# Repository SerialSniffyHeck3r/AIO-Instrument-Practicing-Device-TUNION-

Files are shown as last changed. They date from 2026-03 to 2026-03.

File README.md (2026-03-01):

# STM32F4 Portable Practice DSP Device

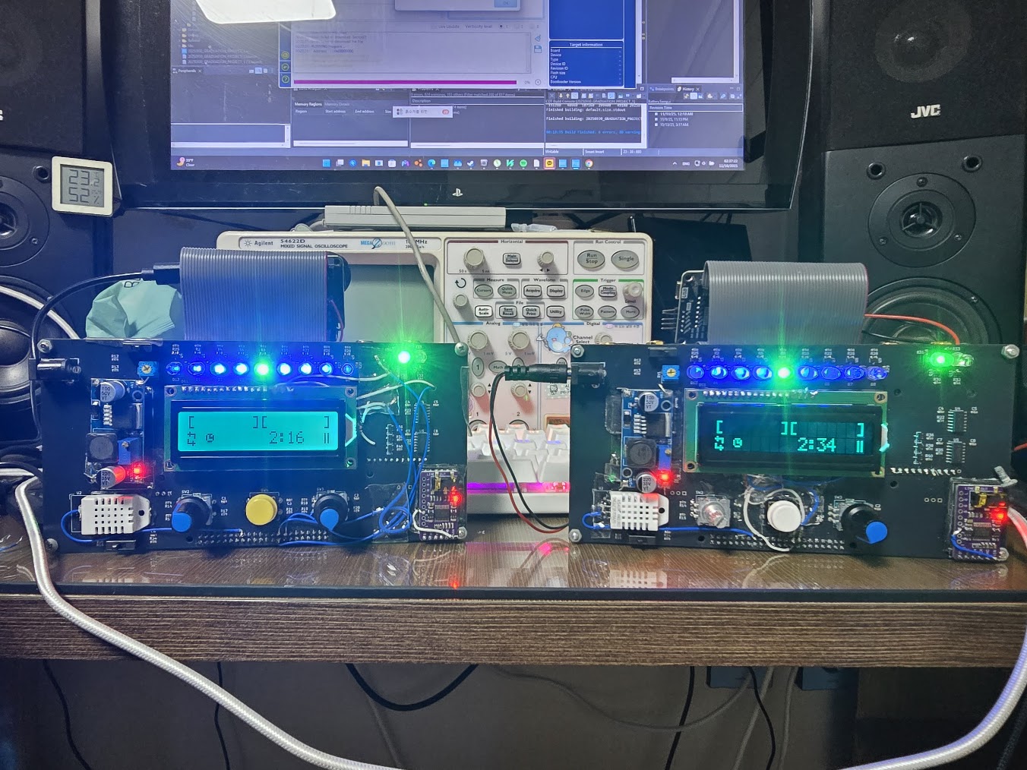
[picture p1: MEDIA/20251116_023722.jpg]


## Videos

https://www.youtube.com/watch?v=_CYvJwdOhUQ  Recovering Data

https://www.youtube.com/watch?v=7vPy3JID6l4  System Settings

https://www.youtube.com/watch?v=G-kPSslMNc0  BPM Auto Calculation

https://www.youtube.com/watch?v=HqbBY2KLgDY  Hardware Self Test

https://www.youtube.com/watch?v=8V4moodQUs4  Music Play Mode

https://www.youtube.com/watch?v=r6egSswZjCg  Notch Filter Applied

https://www.youtube.com/watch?v=-oUxMyITEes  Pitch Shifter Applied

https://www.youtube.com/watch?v=r_tZYo8vfbs  Volume Sound Effect

## Overview

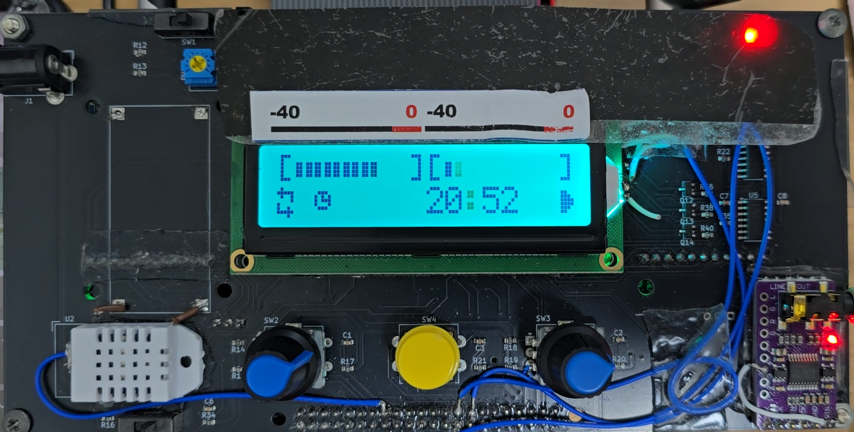
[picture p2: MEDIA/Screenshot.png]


This was developed for my bachelor graduation project, but with keeping in mind that the device will be used personally.. or crowdfunded.
It turned out it wasn't that good to be crowdfunded.. but still it works! and also good for my personal use.

This project focuses on developing a **portable practice companion** built around an **STM32F407** microcontroller.  
The device helps people practice instruments at home or in a rehearsal room without that huge amount of bulky gears.

## TL;DR (for recruiters)

- **Platform:** STM32F407, dual I2S audio, RGB 16x2 LCD, LED bar, rotary encoder, Li-ion battery
- **Focus:** Real-time audio DSP for instrument practice (notch filter, pitch shift, mixer), tuner, metronome
- **Reliability:** Flash config storage with CRC and wear-leveling, backup SRAM snapshot, factory self-test mode
- **Result:** Fully working handheld prototype with custom PCB, firmware, and UX

## STM32F4 기반 악기 연습 장치 'Tunion': 한국어 설명

해당 레포지토리는 본인의 졸업 작품으로써 설게한 제품에 대해 다루고 있습니다.

가정 및 연습실 환경에서는 악기를 크게 연주할 수 없어 뮤트를 착용하거나 전자 악기를 연주하게 된다는 문제 의식에서 출발하였으며, 악기 케이스에 항상 휴대하고 다닐 수 있으면서 악기를 연주할 때 바로 꺼내서 사용할 수 있는 만능 장비를 목표로 개발되었습니다. 
- 반주를 듣고, 반주가 없을 때 아무 음원이나 틀어서 Notch Filter를 적용하여 본인이 연주하는 악기 대역만 잘라서 그 부분과 본인의 악기 소리를 같이 들으면서 연습하거나
- 비트 및 서브비트 등 다양한 기능이 포함된 메트로놈 소리를 들으면서 반주도 같이 듣고 그 소리에 맞춰 악기를 연습하거나
- 악기를 조율하거나
- 또는 악기를 적절한 온습도의 환경에서 보관할 수 있게 하는 것

을 목표로 두고 있습니다.

본 기기의 기능은 다음과 같습니다:
- 악기로부터 들어오는 악기 소리 아날로그 입력 / 음향기기로부터 들어오는 반주 입력을 믹싱 및 개별 볼륨 조절
- 반주에서 본인이 연주하고자 하는 악기 대역을 자를 수 있는 Notch Filter를 적용해서 악기 소리와 믹싱
- HSE를 통해 달성한 고정밀 메트로놈, Sub-Beat, Tap Tempo, 리타르단도 기능을 포함하는 시중에도 찾아보기 힘든 다기능 메트로놈
- 악기 튜너 및 펑션 제너레이터
- 환경설정 및 Flash와 백업 SRAM에 환경설정 다중 백업
- Real-Time Clock, 연습 시간 기록 기능
- 실제 생산을 위한 하드웨어 셀프 테스트 (RAM, Flash 접근 시간 테스트, LCD 및 오디오 출력 테스트)
- 스스로의 펌웨어를 알아서 '죽이는' 히든 커맨드

### 기기 내부 저장 방식

본인을 레트로 컴퓨팅에 관심이 많으며, 레트로 컴퓨팅을 연구하거나 임베디드 시스템을 개인적으로 연구하면서 생긴 아이디어를 적용했습니다.

MCU와 내부 RAM이 살아 있는 상황에서
- Flash에 저장하는 경우: 홈 화면으로 복귀 / 절전 모드에서 탈출했을 때 설정 값이 이전과 변화했을 경우에만 Write
- BKPSRAM에 저장하는 경우: 모든 버튼이 조작되었을 때. Overhead가 낮아 최대 1초에 30번을 조작해도 시스템의 동작 안정성을 저해하지 않는다는 판단.

전원이 완전히 차단되었으나 백업 전지는 살아 있는 경우:
- 전원 인가시 BKPSRAM의 값 확인 후, Magic Number (0xDEADBEEF) Check
- 백업 전지가 살아 있으므로 Magic Number가 그대로 있으므로 유효하다고 판단하여, BKPSRAM에서 바로 값을 불러옴

전원이 완전히 차단되고 백업 배터리까지 빠졌을 경우:
- 전원 인가시 BKPSRAM의 값 확인 후 Magic Number가 유효하지 않음을 확인
- 사용자에게 Recover Data? YES / NO 인터페이스를 통해, 백업 배터리 분리가 초기화를 위한 의도적 행동인지 확인.
- 만약 YES를 선택했을 경우, FLASH에서 값을 복원. NO를 선택했을 경우 시스템 설정이 출고 시와 동일하게 초기화됨.
- 어차피 백업 배터리가 분리되었으면 **당연히** RTC도 유효하지 않을 것이므로, Yes / No 선택 유무에 상관없이 시계 재설정 유도
- 이후 정상 부팅 

---

## Backstory

I play lots of instrument from woodwinds to percussion. Music is pretty much literally my life. 
When I practice guitar or other instruments at home, 
I usually need shitloads of separate devices: audio interface, mixer, tuner, metronome, maybe a laptop? a phone??

So this is the backstory. I just wanted a **single small device** that can do all of these, while maintaining the functionality.
This is a graduation project, but my intention was to make something that is actually useful and is potentially lucrative.

The function that I planned to implement was:
- mix backing track and my instrument,
- remove some frequency range (for example vocals),
- quickly transpose the song,
- show audio level
- tuner and metromone with lots of features
- features that every portable embedded device that is on sale should have

So I designed and built this device as my **bachelor graduation project**.

---

## What this device does

From a user point of view, this box is:

- A **small mixer** for two stereo audio sources
- A **practice helper** that can cut or change a specific frequency band, then mix audio with my instrument sound
- A **digital tuner** with 1 cent resolution
- A **metronome** with different time signatures and tempo changes
- A **status monitor** for battery, temperature, humidity and system state

All of this runs on one STM32F407 MCU with no external DSP chip.

---

## Main features

### 1. Real-time audio DSP pipeline

- Two I2S inputs (for example: backing track + instrument/mic)
- DMA double-buffered ring pipeline (16-bit audio → float → processed → 16-bit)
- **Real-time mixing** of both channels with:
  - 50-step digital volume for each channel
  - master volume and balance
  - dBFS level meters for input level check

### 2. Adjustable band-cut / notch filter for practice

- User can select a **frequency range to cut** (for example vocal range)
- Implemented with **ARM CMSIS-DSP IIR biquad filters**
- Supports:
  - on/off control from the UI
  - start / end frequency
  - **three user presets** per instrument (saved in non-volatile memory)

This lets me listen to a song while removing or reducing the part I want to practice over.

### 3. Simple pitch shift for fast transposition

- Integrated **pitch shift** engine for quick transpose
- Control in **semitones** (for example −3…+3)
- Focus is on **low latency** and “good enough for practice”,  
  not studio-quality offline processing

### 4. Integrated tuner

- **Digital chromatic tuner** with 1-cent resolution
- AMDF-based pitch detection with:
  - harmonic / octave correction
  - pre-lock and lock logic to avoid jumping notes
- Adjustable:
  - **A4 base frequency** (calibration)
  - input sensitivity

The tuner drives both the LCD and the LED bar for visual feedback.

### 5. Sample-accurate metronome & tone generator

- Metronome audio is generated **inside the same DSP pipeline** as the audio
- Features:
  - accents and sub-clicks
  - tempo changes (ritardando / accelerando / back to a-tempo)
  - separate metronome volume
- Extra **sound generator mode** (sine / square / triangle)  
  for tuning or quick tests.

### 6. User interface and UX

- **RGB 16x2 character LCD** (HD44780-compatible)
  - custom UI pages for each mode (practice, tuner, metronome, settings)
- **LED bar** driven by PWM:
  - VU meter for input / mic levels
  - tuner center indication
  - metronome visualization
- **Rotary encoder + buttons**:
  - used for navigation and parameter editing
  - single short/long click design so it can be used while holding an instrument

I tried to keep the UI simple enough to use with one hand.

### 7. Power, environment and settings

- Powered from a **single Li-ion battery**
- Battery:
  - voltage measurement and level estimation
  - low-battery handling
- **Temperature & humidity** sensor (DHT22):
  - shows instrument storage environment
- **Config storage:**
  - main storage in Flash (sector with custom format)
  - record format with version, sequence number and CRC32
  - background service that only writes when values changed
- **Backup snapshot:**
  - second copy in backup SRAM,  
    so the device can restore settings quickly after a battery change

### 8. Factory / test mode

- Hidden button combo opens a **self-test mode**
- Used for:
  - LCD and LED test
  - audio path test
  - peripheral checks
- This was designed with **future production / repair** in mind.

---

## Hardware overview

- MCU: **STM32F407** (Cortex-M4 with FPU and DSP extensions)
- Audio:
  - Dual I2S interface
  - 16-bit stereo in/out
- UI:
  - HD44780-compatible RGB 16x2 LCD
  - 10-segment (or similar) LED bar
  - rotary encoder + buttons
- Sensors:
  - DHT22 temperature / humidity
  - battery voltage measurement
- Power:
  - Li-ion battery
  - backup power for RTC and SRAM

Custom PCB was designed so that the device is actually **hand-held and portable**. 

---

## Firmware / code structure (short version)

The firmware is written in **C** using the STM32 HAL and CMSIS-DSP.

- `main.c`  
  - main UI state machine, mode handling, LCD updates
- `notch.c`  
  - audio DSP pipeline, I2S callback, mixing, notch filter, pitch shift, metronome, sound generator
- `tuner.c`  
  - pitch detection and note / cent calculation
- `LEDcontrol.c`  
  - LED bar effects, VU meter and tuner / metronome visualization
- `BatteryTemp.c`, `dht.c`  
  - battery and DHT22 handling
- `PowerFlash.c`  
  - Flash config storage with CRC and wear-leveling
- `PowerSave.c`  
  - backup SRAM snapshot for fast resume
- `Clock.c`  
  - RTC time setting UI

The code is clearly not perfect, as this is one of my first huge system architect project.
but it is a complete prototype that I could really use as my **daily practice companion**.

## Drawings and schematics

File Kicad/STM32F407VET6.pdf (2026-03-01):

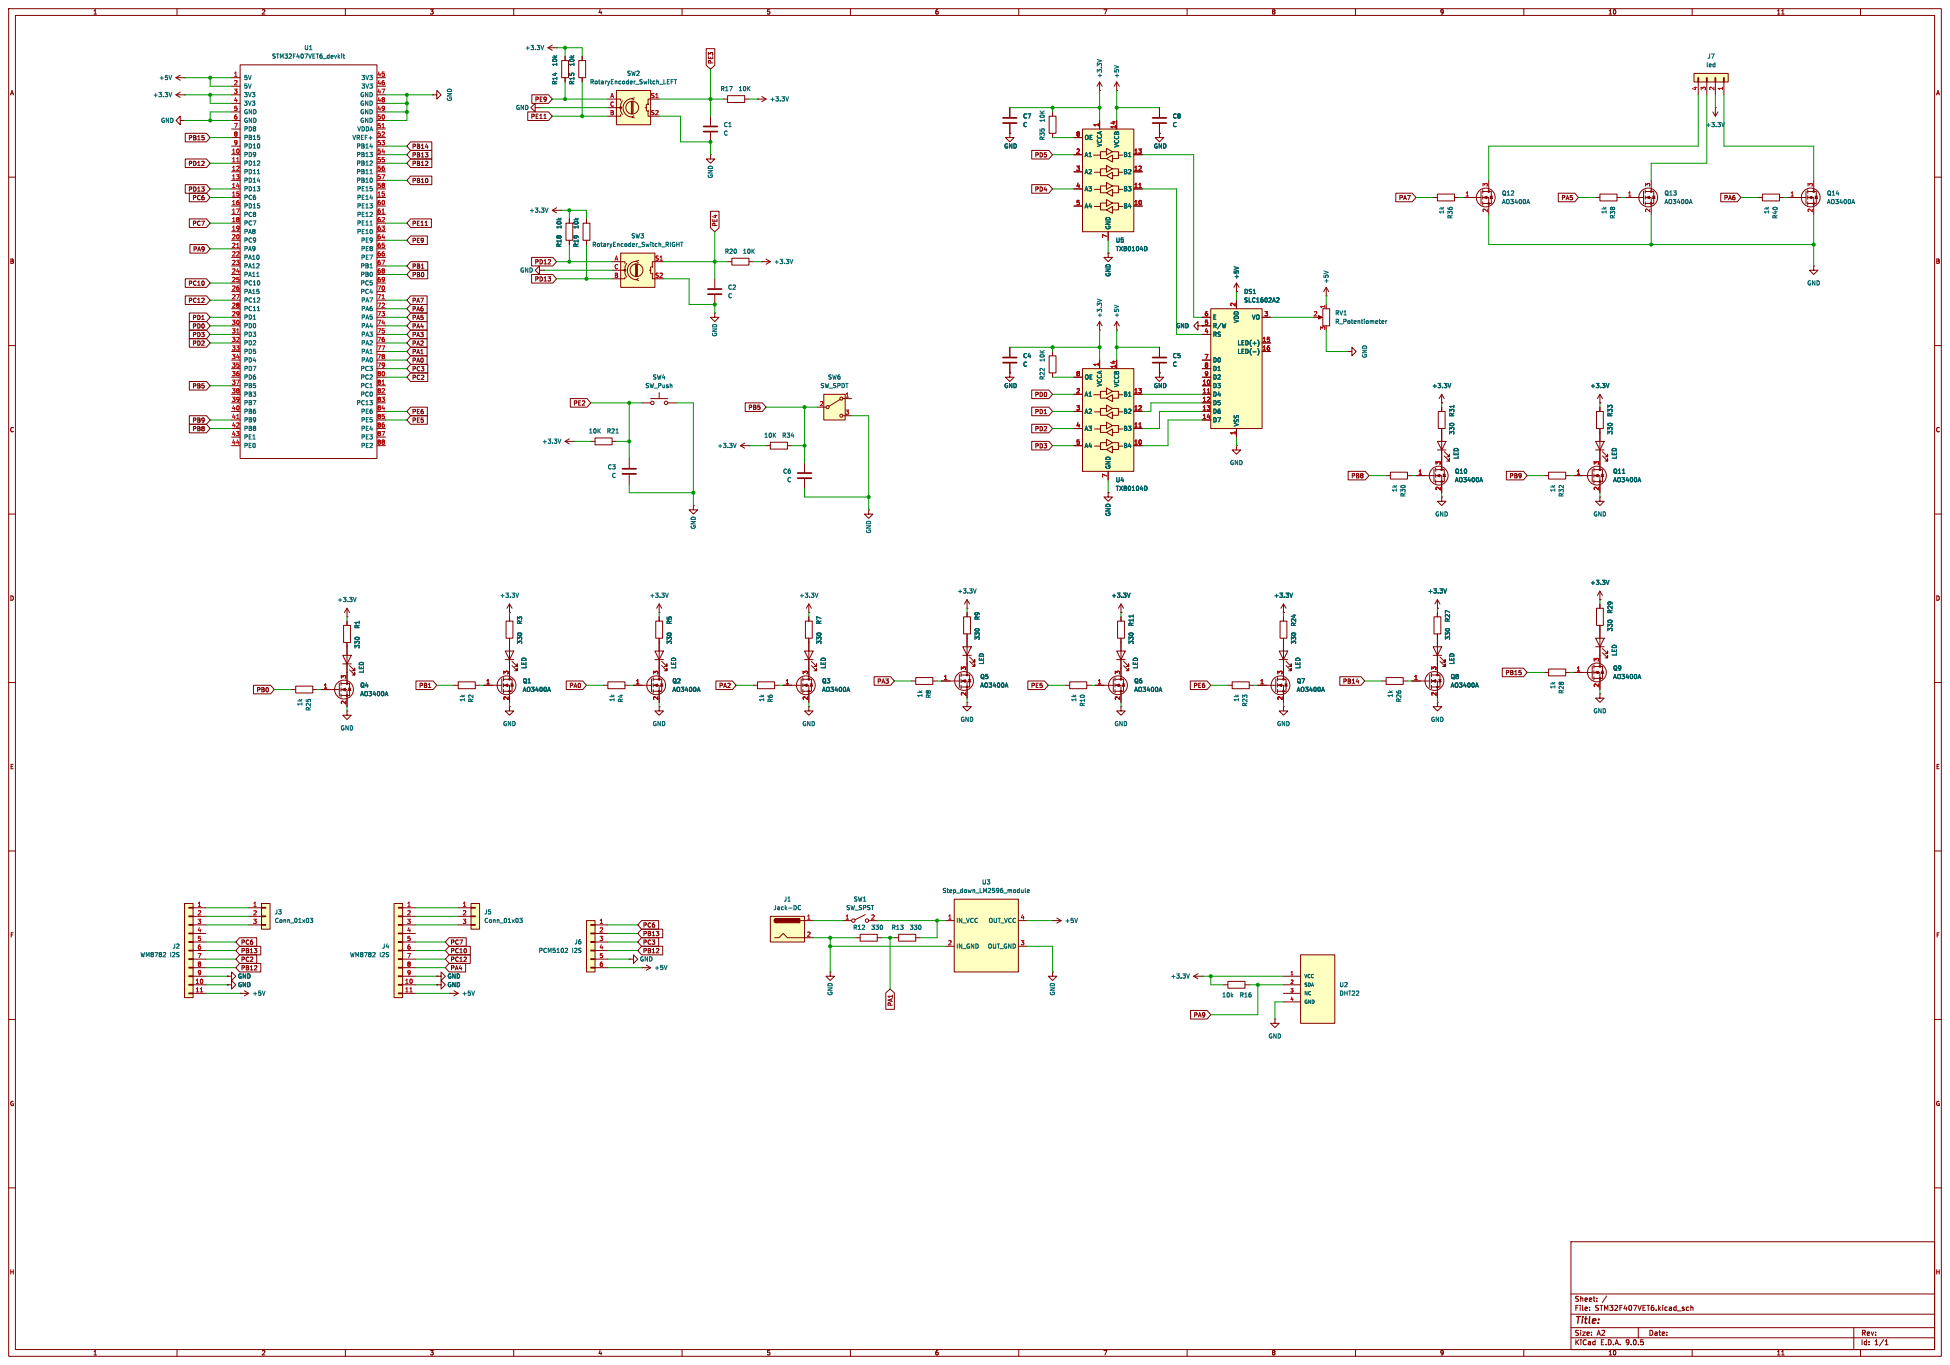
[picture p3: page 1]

3V3 46 GND 47 GND 48 GND 49 GND 50 VDDA 51 VREF+ 52 PB14 53 PB13 54 PB12 55 PB11 56 PB10 57 PE15 58 PE14 15 PE13 60 PE12 61 PE11 62 PE10 63 PE9 64 PE8 65 PE7 66 PB1 67 PB0 68 PC5 69 PC4 70 PA7 71 PA6 72 PA5 73 PA4 74 PA3 75 PA2 76 PA1 77 PA0 78 PC3 79 PC2 80 PC1 81 PC0 82 PC13 83 PE6 84 PE5 85 PE4 86 PE3 87 PE2 88

3 2 Q7 AO3400A GND GND GND GND GND

3 2 LED R1 330 GND GND GND GND R3 330 LED R5 330 LED Q2 AO3400A

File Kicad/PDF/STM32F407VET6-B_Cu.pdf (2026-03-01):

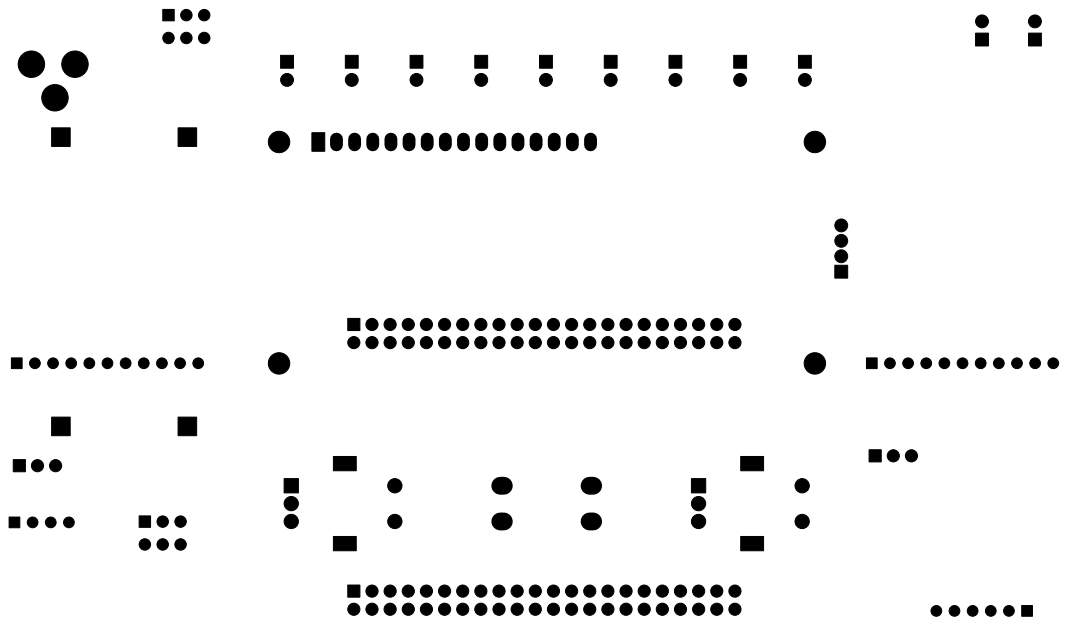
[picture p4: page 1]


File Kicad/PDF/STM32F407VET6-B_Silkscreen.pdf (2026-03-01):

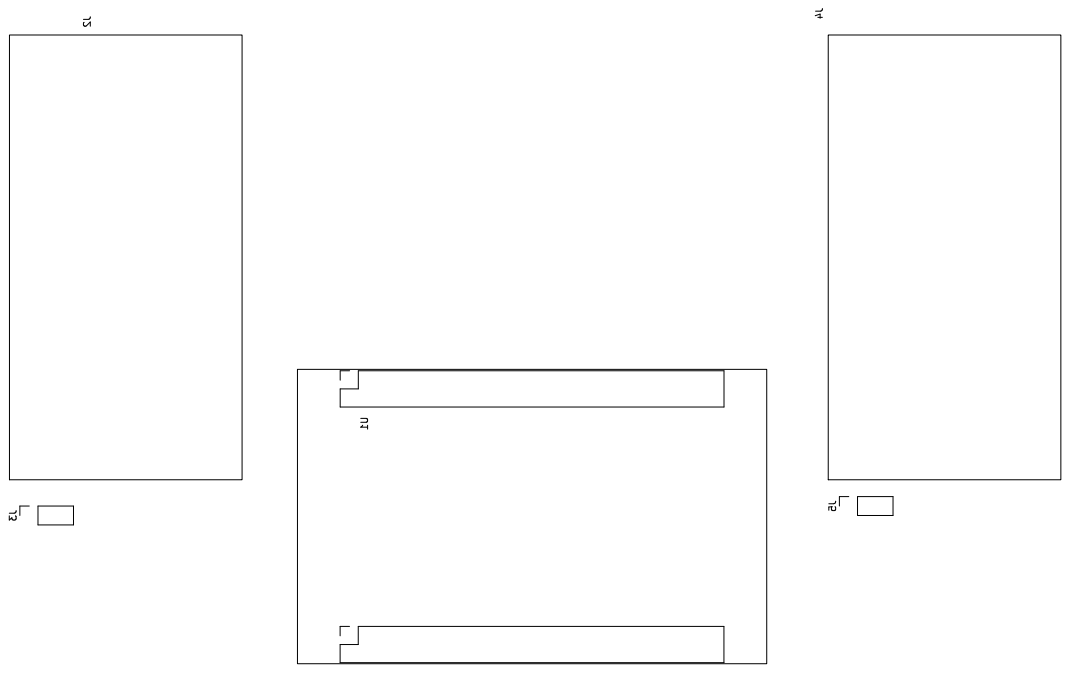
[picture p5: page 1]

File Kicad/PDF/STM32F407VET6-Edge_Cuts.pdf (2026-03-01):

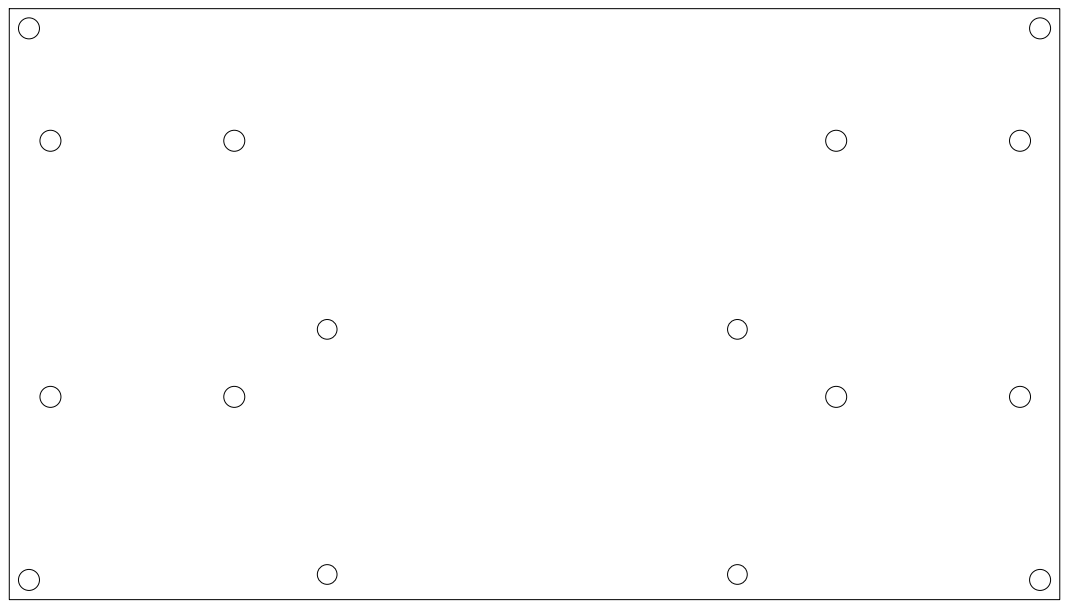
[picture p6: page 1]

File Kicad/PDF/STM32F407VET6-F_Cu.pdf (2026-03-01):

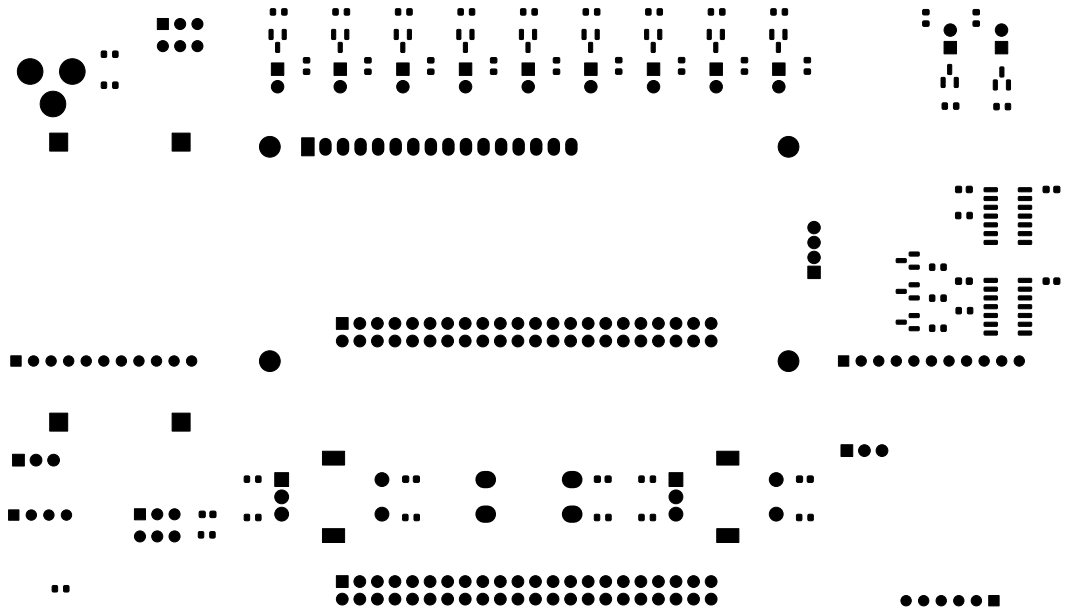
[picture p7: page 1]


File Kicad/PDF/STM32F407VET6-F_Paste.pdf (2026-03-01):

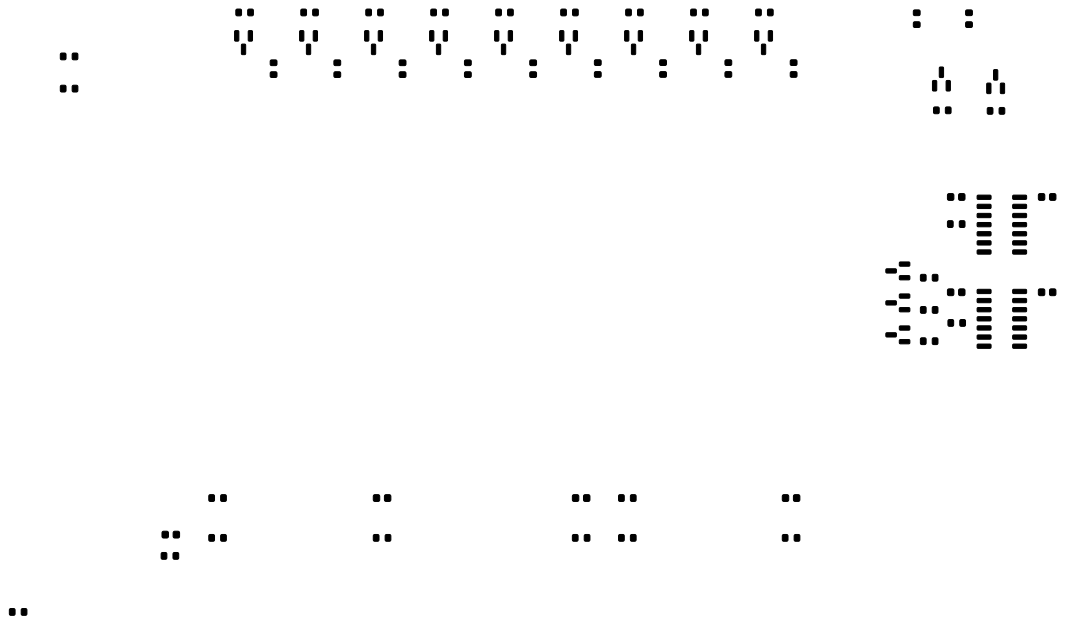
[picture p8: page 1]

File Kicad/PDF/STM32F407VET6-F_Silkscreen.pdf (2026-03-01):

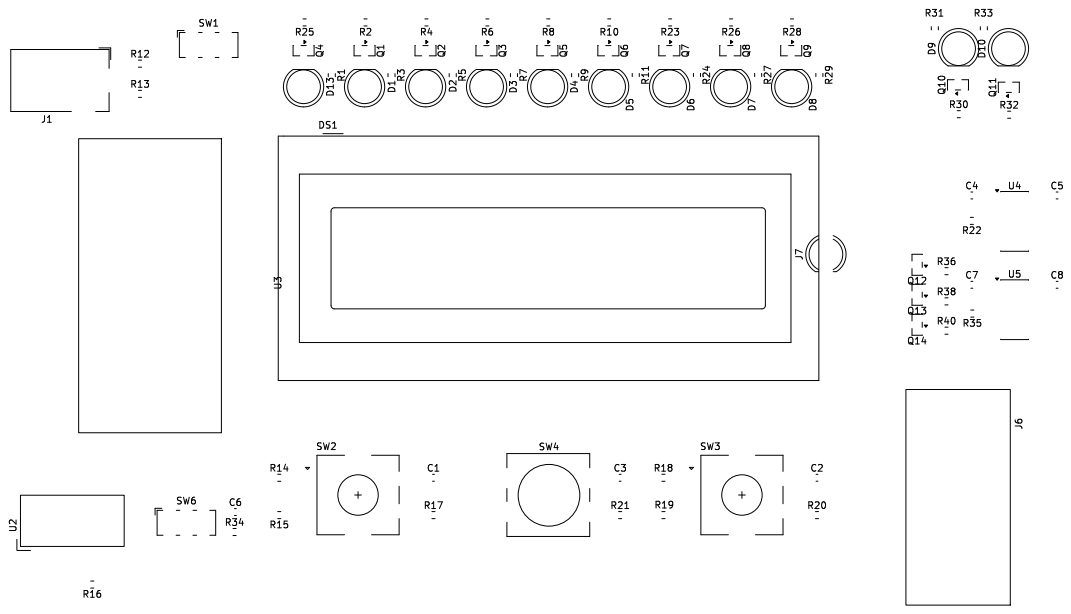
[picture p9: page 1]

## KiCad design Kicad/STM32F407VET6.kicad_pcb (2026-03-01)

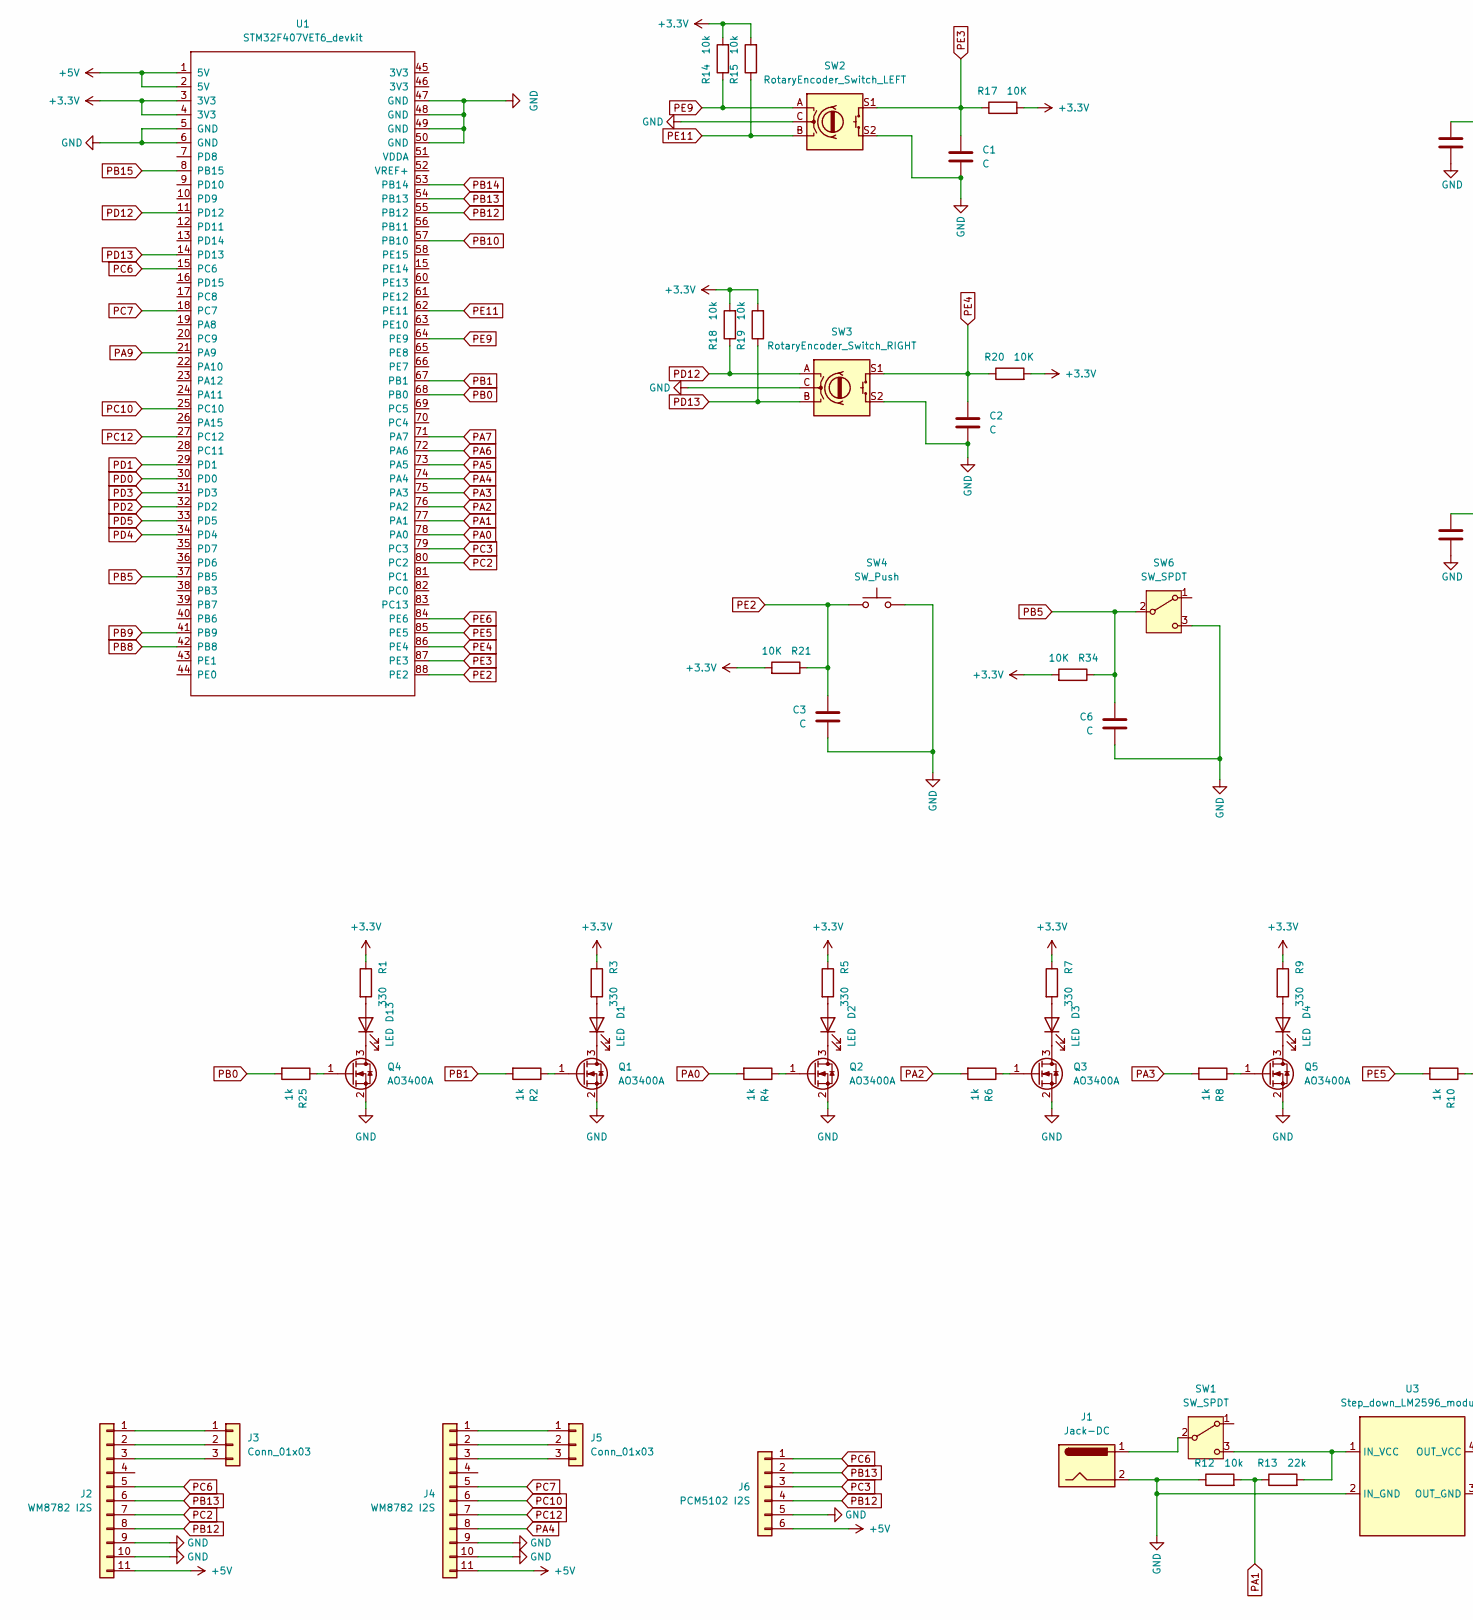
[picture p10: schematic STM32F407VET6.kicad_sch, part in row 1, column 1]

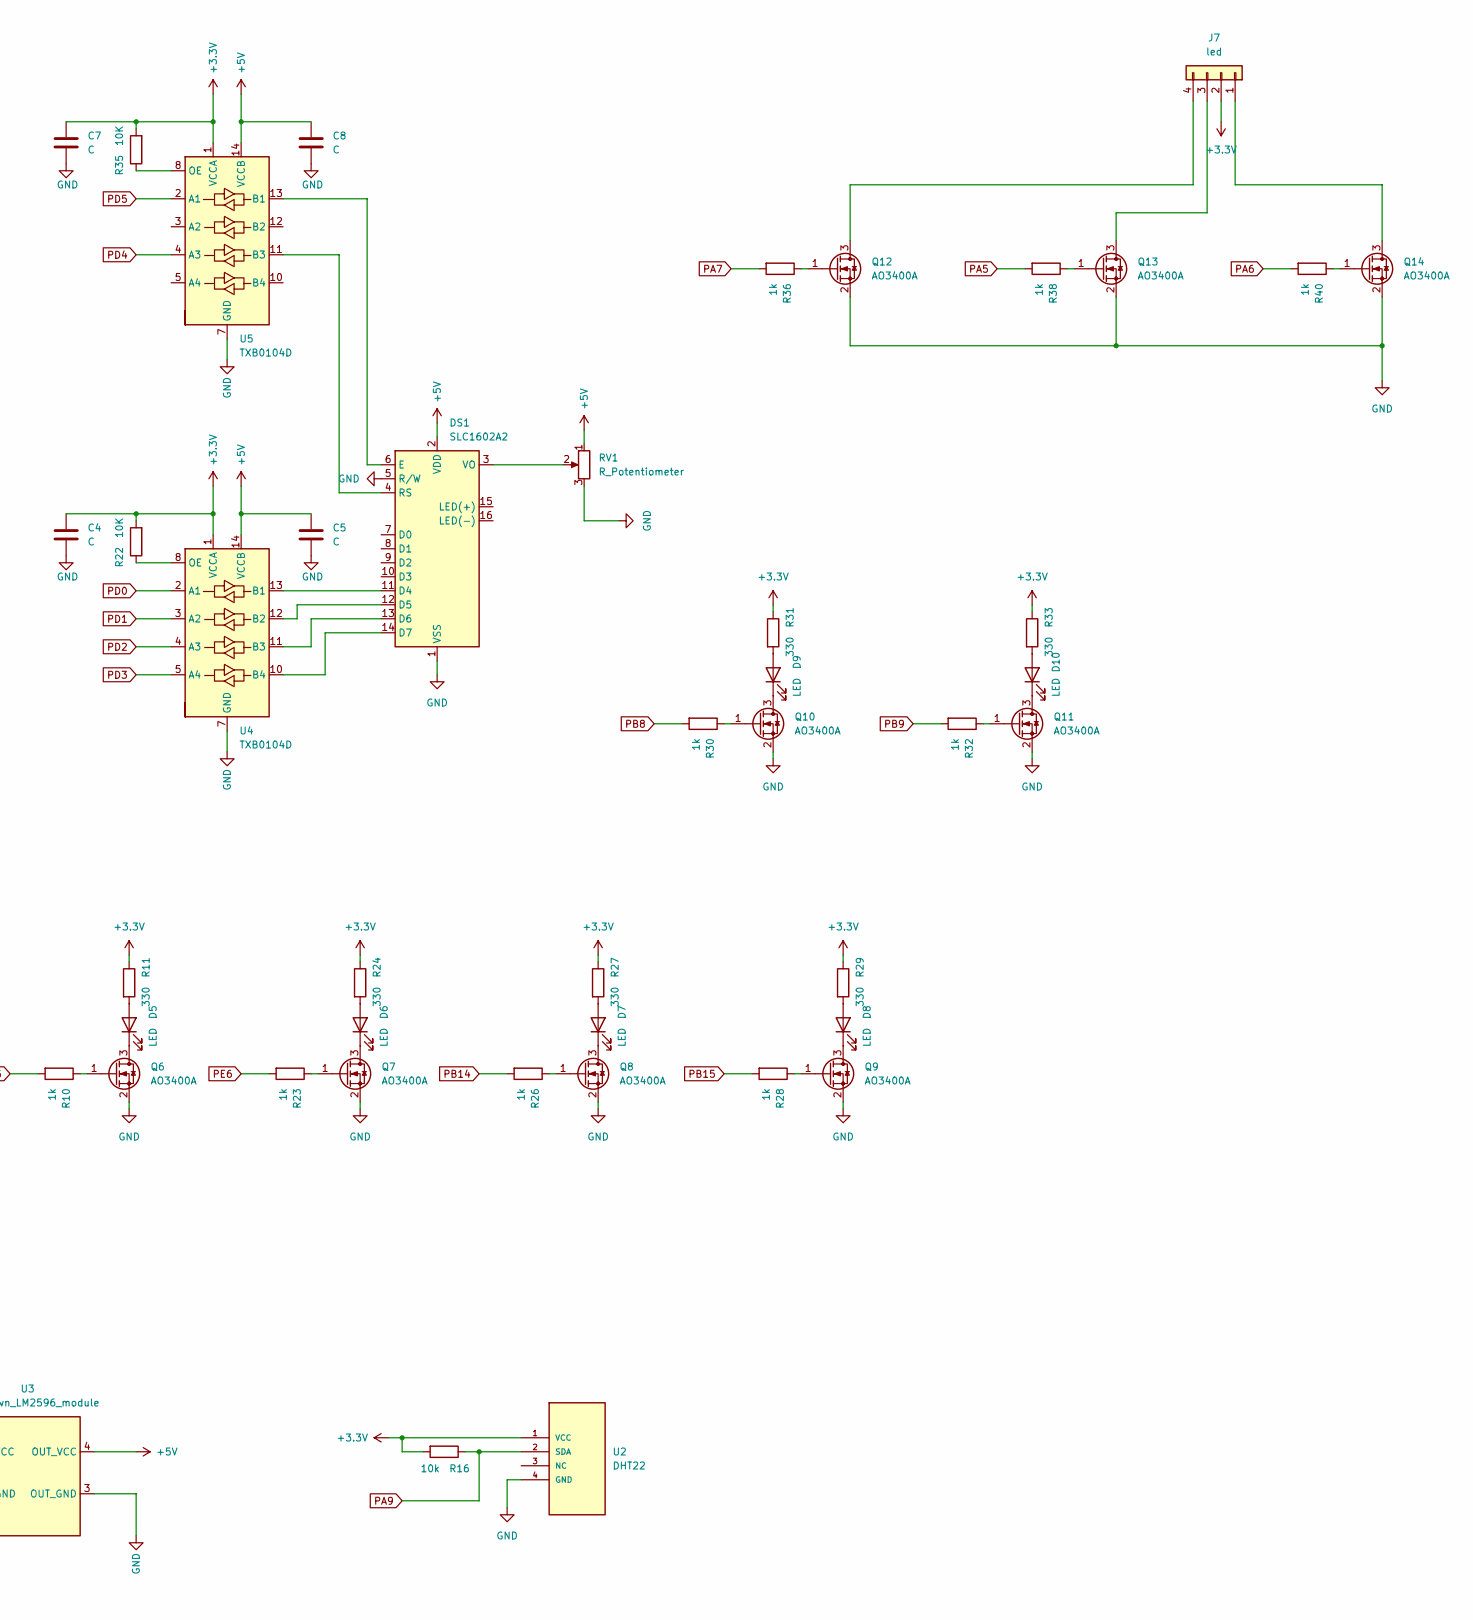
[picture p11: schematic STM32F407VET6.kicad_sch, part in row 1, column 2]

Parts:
C1, C2, C3, C4, C5, C6, C7, C8: C; C_0603_1608Metric
D1, D2, D3, D4, D5, D6, D7, D8, D9, D10, D13: LED; LED_D5.0mm
DS1: SLC1602A2; WC1602A
J1: Jack-DC; BarrelJack_CUI_PJ-102AH_Horizontal
J2, J4: WM8782 I2S; wholesale I2S ADC
J3, J5: Conn_01x03; PinHeader_1x03_P2.54mm_Vertical
J6: PCM5102 I2S; PCM5102A DAC
J7: led; LED_D5.0mm-4_RGB_Wide_Pins
Q1, Q2, Q3, Q4, Q5, Q6, Q7, Q8, Q9, Q10, Q11, Q12, Q13, Q14: AO3400A; SOT-23
R1, R3, R5, R7, R9, R11, R24, R27, R29, R31, R33: 330; R_0603_1608Metric
R2, R4, R6, R8, R10, R23, R25, R26, R28, R30, R32, R36, R38, R40: 1k; R_0603_1608Metric
R12, R14, R15, R16, R18, R19: 10k; R_0603_1608Metric
R13: 22k; R_0603_1608Metric
R17, R20, R21, R22, R34, R35: 10K; R_0603_1608Metric
RV1: R_Potentiometer; Potentiometer_Vishay_T73YP_Vertical
SW1, SW6: SW_SPDT; SW_slide_3
SW2: RotaryEncoder_Switch_LEFT; RotaryEncoder_Alps_EC11E-Switch_Vertical_H20mm
SW3: RotaryEncoder_Switch_RIGHT; RotaryEncoder_Alps_EC11E-Switch_Vertical_H20mm
SW4: SW_Push; SW_PUSH-12mm_Wuerth-430476085716
U1: STM32F407VET6_devkit; STM32F407_DEV_KIT
U2: DHT22
U3: Step_down_LM2596_module; DCDC_LM2596
U4, U5: TXB0104D; SOIC-14_3.9x8.7mm_P1.27mm

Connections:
+3.3V: C4.1, C7.1, J7.2, R1.1, R3.1, R5.1, R7.1, R9.1, R11.1, R14.2, R15.2, R16.2, R17.2, R18.2, R19.2, R20.2, R21.2, R22.2, R24.1, R27.1, R29.1, R31.1, R33.1, R34.2, R35.2, U1.3 (3V3), U1.4 (3V3), U2.1 (VCC), U4.1 (VCCA), U5.1 (VCCA)
+5V: C5.1, C8.1, DS1.2 (VDD), J2.11, J4.11, J6.6, RV1.1, U1.1 (5V), U1.2 (5V), U3.4 (OUT_VCC), U4.14 (VCCB), U5.14 (VCCB)
GND: C1.2, C2.2, C3.2, C4.2, C5.2, C6.2, C7.2, C8.2, DS1.1 (VSS), DS1.5 (R/W), J1.2, J2.9, J2.10, J4.9, J4.10, J6.5, Q1.2 (S), Q2.2 (S), Q3.2 (S), Q4.2 (S), Q5.2 (S), Q6.2 (S), Q7.2 (S), Q8.2 (S), Q9.2 (S), Q10.2 (S), Q11.2 (S), Q12.2 (S), Q13.2 (S), Q14.2 (S), R12.1, RV1.3, SW2.C, SW2.S2, SW3.C, SW3.S2, SW4.2, SW6.3 (C), U1.5 (GND), U1.6 (GND), U1.47 (GND), U1.48 (GND), U1.49 (GND), U1.50 (GND), U2.4 (GND), U3.2 (IN_GND), U3.3 (OUT_GND), U4.7 (GND), U5.7 (GND)
unnamed: D1.2 (A), R3.2
unnamed: D1.1 (K), Q1.3 (D)
unnamed: D2.2 (A), R5.2
unnamed: D2.1 (K), Q2.3 (D)
unnamed: D3.2 (A), R7.2
unnamed: D3.1 (K), Q3.3 (D)
unnamed: D4.2 (A), R9.2
unnamed: D4.1 (K), Q5.3 (D)
unnamed: D5.2 (A), R11.2
unnamed: D5.1 (K), Q6.3 (D)
unnamed: D6.2 (A), R24.2
unnamed: D6.1 (K), Q7.3 (D)
unnamed: D7.2 (A), R27.2
unnamed: D7.1 (K), Q8.3 (D)
unnamed: D8.2 (A), R29.2
unnamed: D8.1 (K), Q9.3 (D)
unnamed: D9.2 (A), R31.2
unnamed: D9.1 (K), Q10.3 (D)
unnamed: D10.2 (A), R33.2
unnamed: D10.1 (K), Q11.3 (D)
unnamed: D13.2 (A), R1.2
unnamed: D13.1 (K), Q4.3 (D)
unnamed: DS1.11 (D4), U4.13 (B1)
unnamed: DS1.12 (D5), U4.12 (B2)
unnamed: DS1.13 (D6), U4.11 (B3)
unnamed: DS1.14 (D7), U4.10 (B4)
unnamed: DS1.6 (E), U5.13 (B1)
unnamed: DS1.4 (RS), U5.11 (B3)
unnamed: DS1.3 (VO), RV1.2
unnamed: J2.1, J3.1
unnamed: J2.2, J3.2
unnamed: J2.3, J3.3
unnamed: J4.1, J5.1
unnamed: J4.2, J5.2
unnamed: J4.3, J5.3
unnamed: J7.1, Q14.3 (D)
unnamed: J7.3, Q13.3 (D)
unnamed: J7.4, Q12.3 (D)
unnamed: Q1.1 (G), R2.1
unnamed: Q2.1 (G), R4.1
unnamed: Q3.1 (G), R6.1
unnamed: Q4.1 (G), R25.1
unnamed: Q5.1 (G), R8.1
unnamed: Q6.1 (G), R10.1
unnamed: Q7.1 (G), R23.1
unnamed: Q8.1 (G), R26.1
unnamed: Q9.1 (G), R28.1
unnamed: Q10.1 (G), R30.1
unnamed: Q11.1 (G), R32.1
unnamed: Q12.1 (G), R36.1
unnamed: Q13.1 (G), R38.1
unnamed: Q14.1 (G), R40.1
unnamed: J1.1, SW1.2 (B)
unnamed: R13.2, SW1.3 (C), U3.1 (IN_VCC)
unnamed: R22.1, U4.8 (OE)
unnamed: R35.1, U5.8 (OE)
PA0: R4.2, U1.78 (PA0)
PA1: R12.2, R13.1, U1.77 (PA1)
PA2: R6.2, U1.76 (PA2)
PA3: R8.2, U1.75 (PA3)
PA4: J4.8, U1.74 (PA4)
PA5: R38.2, U1.73 (PA5)
PA6: R40.2, U1.72 (PA6)
PA7: R36.2, U1.71 (PA7)
PA9: R16.1, U1.21 (PA9), U2.2 (SDA)
PB0: R25.2, U1.68 (PB0)
PB1: R2.2, U1.67 (PB1)
PB5: C6.1, R34.1, SW6.2 (B), U1.37 (PB5)
PB8: R30.2, U1.42 (PB8)
PB9: R32.2, U1.41 (PB9)
PB10: U1.57 (PB10)
PB12: J2.8, J6.4, U1.55 (PB12)
PB13: J2.6, J6.2, U1.54 (PB13)
PB14: R26.2, U1.53 (PB14)
PB15: R28.2, U1.8 (PB15)
PC2: J2.7, U1.80 (PC2)
PC3: J6.3, U1.79 (PC3)
PC6: J2.5, J6.1, U1.15 (PC6)
PC7: J4.5, U1.18 (PC7)
PC10: J4.6, U1.25 (PC10)
PC12: J4.7, U1.27 (PC12)
PD0: U1.30 (PD0), U4.2 (A1)
PD1: U1.29 (PD1), U4.3 (A2)
PD2: U1.32 (PD2), U4.4 (A3)
PD3: U1.31 (PD3), U4.5 (A4)
PD4: U1.34 (PD4), U5.4 (A3)
PD5: U1.33 (PD5), U5.2 (A1)
PD12: R18.1, SW3.A, U1.11 (PD12)
PD13: R19.1, SW3.B, U1.14 (PD13)
PE2: C3.1, R21.1, SW4.1, U1.88 (PE2)
PE3: C1.1, R17.1, SW2.S1, U1.87 (PE3)
PE4: C2.1, R20.1, SW3.S1, U1.86 (PE4)
PE5: R10.2, U1.85 (PE5)
PE6: R23.2, U1.84 (PE6)
PE9: R14.1, SW2.A, U1.64 (PE9)
PE11: R15.1, SW2.B, U1.62 (PE11)

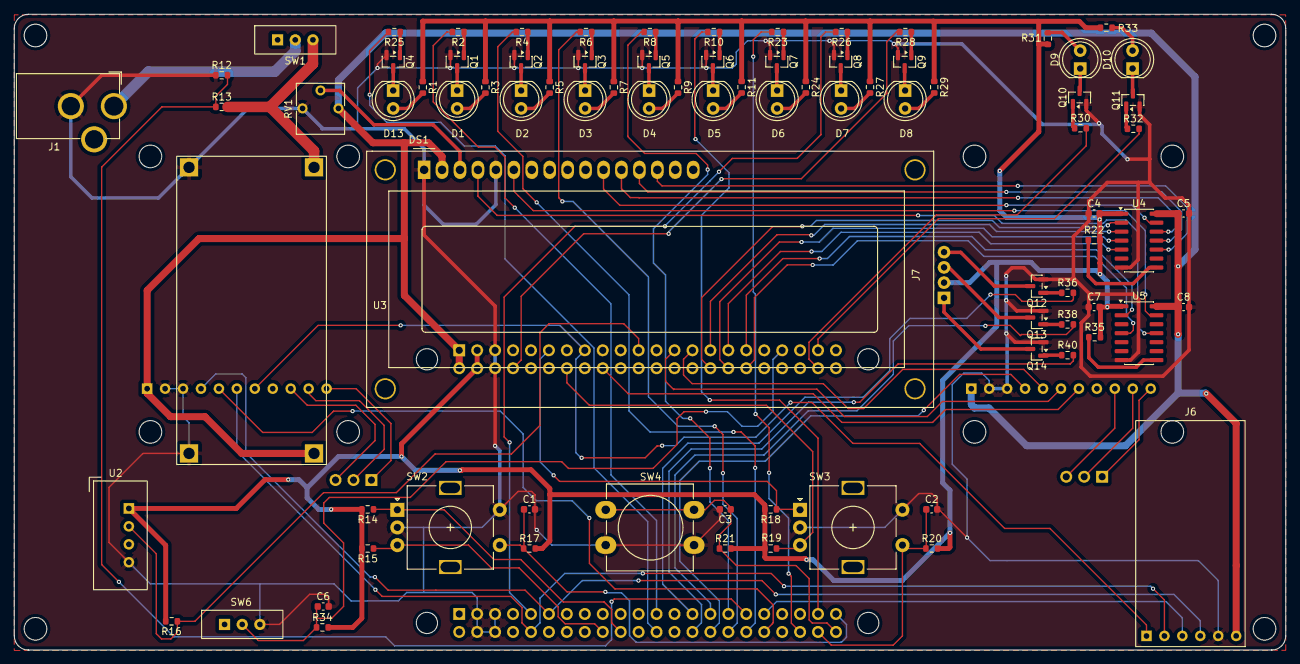
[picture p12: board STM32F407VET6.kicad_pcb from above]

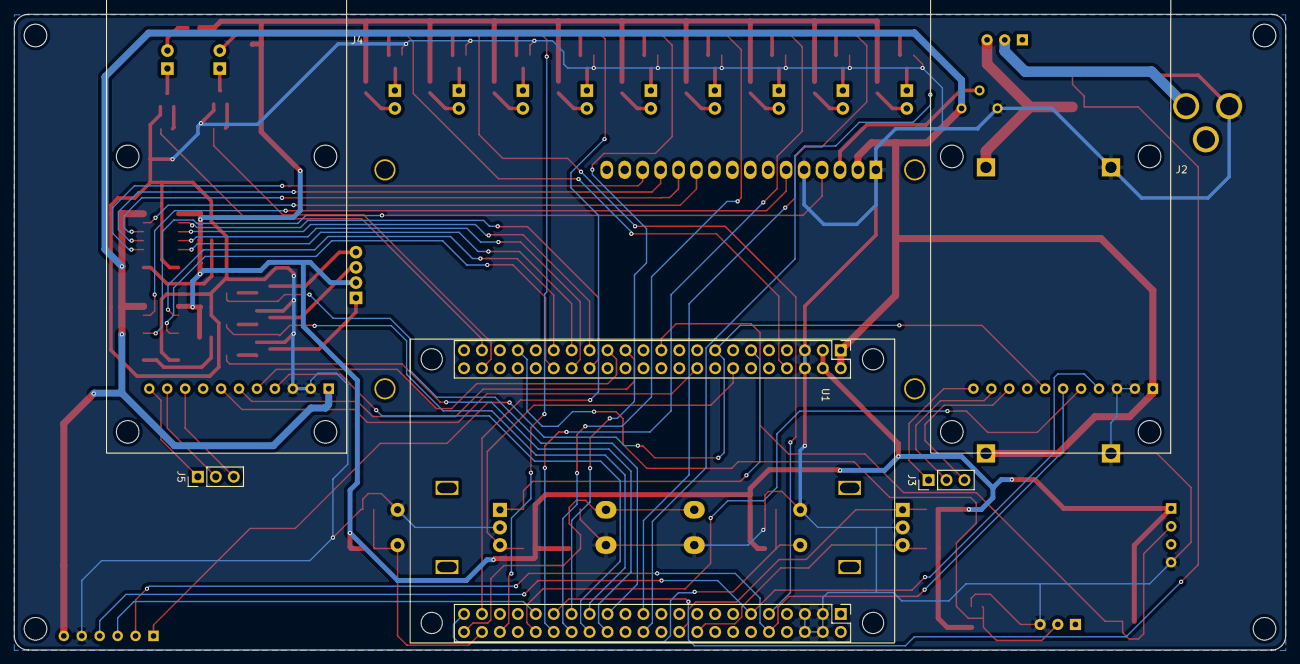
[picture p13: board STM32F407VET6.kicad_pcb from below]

Board: 2 copper layers, 180.0 x 90.0 mm, 90 parts (5 on the bottom side), 98 nets.

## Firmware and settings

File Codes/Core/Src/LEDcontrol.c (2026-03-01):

/* ============================================================================
 * LEDcontrol.c — L2R FLOW (STM32F407)
 *
 * 목표
 *  - 저휘도 계단/플리커 제거: Pre-Gamma(선형) 스무딩 + 감마 보간 + 전 경로 1 kHz
 *  - 기존 API/동작 보존: LED_SetFlowSpeed/Spread/ModeSet()
 *  - 논블로킹, ISR 정수(Q포맷)+LUT (float은 초기화/설정자 한정)
 *  - 타이밍: TIM6=1 kHz(핵심+ΣΔ), TIM7=120 Hz(호환용 no-op)
 *
 * 파이프라인
 *   [전역/상수] → [효과 LUT] → [상태(Q)] → [분배(4탭, Q12 보간)]
 *      → [Pre-Gamma 스무딩(Q20)] → [감마+보간 → PWM(Q16)]
 *      → [ΣΔ → CCR] → [Init/ISR]
 *
 * 섹션 목차
 *   0) 전역 상수/매핑, 외부 핸들
 *   1) 효과 LUT (Gamma/Hann/k(dt), Ease)
 *   2) 상태·버퍼·유틸 (Q 포맷/타이머 유틸 등)
 *   3) 분배 헬퍼(fill_targets_lin_q20_from_pos)
 *   4) 패턴 (Pattern_SweepL2R) & 디스패처(LED_PatternDispatch)
 *   5) 렌더 코어: LED_RenderOneTick (한 틱 전체 수행) + LED_Core_1kHz(래퍼)
 *   6) 모드/ISR (LED_ModeSet, LED_SD_1kHz_ISR 등)
 *   7) 퍼블릭 설정자 (속도/스프레드/스무딩 τ)
 *   8) PWM 초기화 + LED_Init
 *
 * 확장 가이드
 *   - 새 패턴: Pattern_XXX() 추가 → LED_PatternDispatch() case에 매핑
 *   - UI 연동: main.c의 RenderUI()에서 LEDModeSet(번호) 한 줄로 제어
 * ========================================================================== */





#include "main.h"
#include <math.h>
#include <stdint.h>
#include <string.h>

/* forward declarations (패턴/디스패처) */
static inline void Pattern_SweepL2R(uint32_t pos_q88);
void LED_PatternDispatch(uint32_t pos_q88);
static inline void LED_Bar_FromMasterVolume(void);
static inline void LED_Bar_FromSoundBalance(void);
static inline void LED_RenderOneTick(void);
static inline void Pattern_Breath_Center(void);
static inline void LED_Bar_FromNoteIndex(void);
static inline void Pattern_SweepL2R(uint32_t pos_q88);
void LED_PatternDispatch(uint32_t pos_q88);
static inline void LED_Bar_FromMasterVolume(void);
static inline void LED_Bar_FromSoundBalance(void);
static inline void LED_Bar_FromMetronomeVolume(void);   // [ADD]
static inline void LED_RenderOneTick(void);
static inline void Pattern_Breath_Center(void);
static inline void LED_Bar_FromNoteIndex(void);




/* --- 외부 타이머 핸들 (보드 매핑) ----------------------------------------- */
extern TIM_HandleTypeDef htim3;   // TIM3: CH3, CH4  (APB1=84MHz tmrclk)
extern TIM_HandleTypeDef htim5;   // TIM5: CH1, CH3, CH4 (APB1)
extern TIM_HandleTypeDef htim9;   // TIM9: CH1, CH2  (APB2=168MHz tmrclk)
extern TIM_HandleTypeDef htim12;  // TIM12: CH1, CH2 (APB1)

/* 밖에서 오는 것*/
extern volatile uint8_t g_led_brightness_level;

extern volatile uint16_t MasterVolume;   // 0..50
extern volatile uint16_t SoundBalance;   // 0..50

/* === Metronome globals from main.c (read-only) ========================== */
extern volatile uint16_t MetronomeBPM;   /* 30..300 */
extern volatile uint8_t  TimeSignature;  /* 1..9    */
extern volatile uint8_t  IsMetronomeReady;  /* 0/1  */
extern volatile uint8_t  TimeSignatureDen;  /* 1..32  새로 추가 */

/* [NEW] Shared metronome phase (from main.c, Option A) */
extern volatile uint32_t g_met_phi_q16;     // 0..65535
extern volatile uint8_t  g_met_beat_inbar;  // 0..(TimeSignature-1)
extern volatile uint8_t  g_met_ready;       // 0/1

extern volatile uint16_t MetronomeVolume;  // [ADD] 0..50

/* === SoundGen 전역 ================================================ */
/* 현재 음 인덱스: A0=0, A7=7 (main.c에서 관리) */
extern volatile uint8_t CurrentNoteIndex;   /* 0..7 만 사용 */
/* 준비 상태: 1=발진 중(깜빡임 적용), 0=대기(깜빡임 없음) */
extern volatile uint8_t IsSoundGenReady;    /* 0/1 */

/* === [TUNER externs] UI/DSP 공유 변수 === */
extern volatile float    TunerMeasurement;   // 0 이면 미동작(무음/비활성)로 취급
extern volatile uint16_t CurrnetTunerNote;   // 현재 근접 음의 인덱스(참조만)
extern volatile uint16_t CurrentTunerCent;   // -50..+50 (signed로 캐스팅해 사용)

/* === [TUNER 표시 파라미터] === */
volatile uint8_t g_tnr_center_idle_pct = 30;   // 튜너 미동작 시 가운데 LED 최소 밝기(%)
/* [ADD] 좌(I2S2)·우(I2S3) VU 세그먼트(0..30) — 프로젝트 변수명에 맞춰 수정하세요.
   - 내부에서 seg30>=29를 '−3 dBFS 초과'로 봅니다. (−60..0dB → 0..30 선형 매핑 가정) */

// [ADD] VU 세그먼트 가져오는 공식 API
extern void notch_get_vu_segments(uint8_t *outSegL, uint8_t *outSegR); // I2S2 L/R
extern void notch_get_mic_vu_segments(uint8_t *seg_out);               // I2S3 mono

//extern volatile uint16_t s_vu_track30;  // I2S2 쪽 seg30 (예시 변수명)
//extern volatile uint16_t s_vu_mic30;    // I2S3 쪽 seg30 (예시 변수명)

// [ADD] SoundGen 현재 음 인덱스 (main.c에 존재)
extern volatile uint8_t CurrentNoteIndex;  // 0..(NOTE_COUNT-1)

/* ===== 0) 전역 상수/매핑 & 외부 핸들 ===================================== */
#ifndef M_PI
#define M_PI 3.14159265358979323846
#endif

#define NOTE_COUNT 85

/* [옵션] NoteNames 길이를 모듈에서 못 받는다면, 아래 매크로를 파일 상단 어딘가에 둬.
   네 배열(A0..A7)은 총 85개(7옥타브*12 + 1)라서 85가 맞음. 이미 다른 곳에서 정의돼 있으면 이 블록은 무시됨. */
#ifndef SG_NOTE_COUNT
#define SG_NOTE_COUNT 85u
#endif

/* --- Breathing timing (ms) ----------------------------------------------- */
/* 안정 호흡 느낌: 들이쉼 2.8s, 고점홀드 0.7s, 내쉼 3.2s, 저점휴식 0.9s */
#define BREATH_IN_MS       4100u   /* 들이쉼 */
#define BREATH_HOLD_MS      700u   /* 고점에서 잠깐 멈춤 */
#define BREATH_OUT_MS      3800u   /* 내쉼 */
#define BREATH_REST_MS     2000u   /* 저점에서 쉬어가기 */
#define BREATH_TOTAL_MS    (BREATH_IN_MS + BREATH_HOLD_MS + BREATH_OUT_MS + BREATH_REST_MS)

/* 1kHz 한 틱당 +1ms 누적 (ISR 주기가 1ms라 가정) */
static uint32_t s_breath_t_ms = 0;


/* === Pattern params (compile-time knobs) ================================ */
#ifndef MET_BAND_LEDS          /* 한 번에 켜질 LED 개수(2 또는 3 권장) */
#define MET_BAND_LEDS 3u
#endif

#ifndef MET_GROW_FRAC_Q8       /* (0..255) 비트 단위: 성장 구간 비율 (≈0.25) */
#define MET_GROW_FRAC_Q8 64u
#endif
#ifndef MET_SHRINK_FRAC_Q8     /* (0..255) 비트 단위: 수축 구간 비율 (≈0.25) */
#define MET_SHRINK_FRAC_Q8 64u
#endif

#ifndef MET_END_BASE_PERMILLE  /* 끝(1번/9번) LED의 항상-켜짐 기준(퍼밀) */
#define MET_END_BASE_PERMILLE 500u   /* ≈ 50% */
#endif

#ifndef MET_LEN_SLOW_BPM
#define MET_LEN_SLOW_BPM   60u   /* 느리면 +1칸 */
#endif
#ifndef MET_LEN_FAST_BPM
#define MET_LEN_FAST_BPM  140u   /* 빠르면 -1칸 */
#endif
#ifndef MET_LEN_DELTA_MAX
#define MET_LEN_DELTA_MAX   1u   /* 길이 가변 최대폭(칸) */
#endif


// [ADD] LED 모드 번호: 메트로놈 볼륨 바
#ifndef LED_MODE_METRONOME_VOLUME
#define LED_MODE_METRONOME_VOLUME 7u
#endif




/* PWM: 1kHz, 12-bit+ 해상도(ARR=41999 → 약 15.4bit) */
#define PWM_ARR          41999u
#define PWM_MAX          PWM_ARR
#define PWM_HZ           1000u

/* 위치 표현: Q8.8 (1 LED칸 = 256) */
#define QPOS_SHIFT       8

/* 선형밝기 범위(감마 LUT 입력): 0..4096 (Q12) */
#define LIN_MAX          4096u

/* 선형 스무딩 내부 포맷: Q12.8 (정수=0..4096, 분수=8bit) */
#define LIN_FRAC_BITS    8u
#define LIN_Q            (LIN_FRAC_BITS)


// ==== Clip Warn (지속 과레벨만 경고) =========================================
#ifndef LED_MODE_CLIP_WARN
#define LED_MODE_CLIP_WARN  8u
#endif

#define CLIP_SEG_TH              29u   // seg30≥29 ≈ -3 dBFS 초과 (임계 그대로)
#define CLIP_ON_TIME_MS         300u   // 이 시간 이상 연속 초과되어야 'ON'
#define CLIP_OFF_TIME_MS        120u   // 이 시간 이하로 내려오면 'OFF'
#define CLIP_DECAY_PER_FRAME_MS  32u   // 임계 미만일 때 매 프레임 감소(ms)
#define CLIP_BLINK_PERIOD_MS    800u   // 점멸 주기
#define CLIP_BLINK_ON_MS        220u   // 켜짐 구간

#ifndef LED_FRAME_MS
#define LED_FRAME_MS             16u   // 한 프레임 시간(대략)
#endif
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

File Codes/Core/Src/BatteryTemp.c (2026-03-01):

#include "BatteryTemp.h"
#include "main.h"           // HAL_GetTick, 전역 extern들
#include "LCD16X2.h"
#include "LCD16X2_cfg.h"
#include <stdio.h>
#include <string.h>
#include <stdint.h>
#include "dht.h"              // ★ 추가


/* ──────────────────────────────────────────────────────────────
 * degree[] 외부참조 설정
 *  - 권장: main.c의 degree[]에서 static 제거 → extern 사용
 *  - 대안: 아래 매크로 주석 처리 → 로컬 폴백 패턴 사용
 * ────────────────────────────────────────────────────────────── */
#define BATTEMP_USE_EXTERN_DEGREE 1
#ifndef BATTTEMP_DEG_SLOT
#define BATTTEMP_DEG_SLOT 0u
#endif

// ==== DHT22 on PA9, TIM7(us) ====
#define DHT_GPIO_Port   GPIOE
#define DHT_Pin         GPIO_PIN_14

#define MyLCD LCD16X2_1
static DHT_t g_dht;



/* ──────────────────────────────────────────────────────────────
 * 외부 전역값 (main.c에 존재)
 * ────────────────────────────────────────────────────────────── */
extern volatile uint8_t FlashDebug;   // 1이면 텍스트(mV/%), 0이면 그래픽바  :contentReference[oaicite:6]{index=6}
extern uint16_t MainBattADC;          // 배터리 ADC 0..4095               :contentReference[oaicite:7]{index=7}
extern uint16_t Temperature;          // 0.1°C 단위                        :contentReference[oaicite:8]{index=8}
extern uint16_t Humidity;             // 0..99 %                           :contentReference[oaicite:9]{index=9}

extern uint8_t g_dht_req;
extern TIM_HandleTypeDef htim7;   // ★ TIM7 핸들 (tim.c에서 선언)

extern volatile uint8_t TempUnitF;   // 0=C, 1=F
extern volatile uint8_t DHT22_FAIL;  // 1=최근 측정 실패/이상

extern const uint8_t degree[8];  // ← main.c의 degree[] (권장)
extern uint8_t ModeSelectionFirstRunFlag;

extern volatile float Cal_TempC_Offset, Cal_TempC_Scale;
extern volatile float Cal_RH_Offset,   Cal_RH_Scale;
/* ──────────────────────────────────────────────────────────────
 * 사용자 조정 파라미터
 * ────────────────────────────────────────────────────────────── */
#ifndef BATTTEMP_DEFAULT_HOLD_MS
#define BATTTEMP_DEFAULT_HOLD_MS   3000u    // 팝업 유지시간 기본 3초
#endif

#ifndef BATTTEMP_REFRESH_MS
#define BATTTEMP_REFRESH_MS         1000u    // LCD 리프레시 주기(논블로킹)
#endif

#ifndef BATTEMP_HDR_INTERVAL_MS
#define BATTEMP_HDR_INTERVAL_MS         1000u    // LCD 리프레시 주기(논블로킹)
#endif


#ifndef BATTTEMP_DEG_SLOT
#define BATTTEMP_DEG_SLOT             0u    // CGRAM 슬롯(0~7) — ModeSelection에선 0번이 비는 편
#endif



#ifndef BATTTEMP_DEFAULT_HOLD_MS
#define BATTTEMP_DEFAULT_HOLD_MS   3000u
#endif
#ifndef BATTTEMP_REFRESH_MS
#define BATTTEMP_REFRESH_MS         100u
#endif

// ===== 설정(필요 시 숫자만 바꿔도 됨) =====
#ifndef BATTLOW_THRESHOLD_MV
#define BATTLOW_THRESHOLD_MV     3200u   // 저전압 임계(mV) — 보드에 맞게 조정
#endif
#ifndef BATTLOW_CHECK_PERIOD_MS
#define BATTLOW_CHECK_PERIOD_MS   100u   // 감시 주기
#endif
#ifndef BATTLOW_FLASH_MS
#define BATTLOW_FLASH_MS          300u   // "LOW" 경고 시 빨강 유지 시간
#endif
#ifndef BATTLOW_EXIT_OK_HYST_MS
#define BATTLOW_EXIT_OK_HYST_MS  1000u   // 임계 이상 유지해야 통과하는 시간
#endif
#ifndef POWER_ON_DELAY_MS
#define POWER_ON_DELAY_MS        3000u   // 통과 후 전원 켜기까지 대기(3초)
#endif
/* ──────────────────────────────────────────────────────────────
 * 로컬 상태
 * ────────────────────────────────────────────────────────────── */
static uint8_t  s_active      = 0;
static uint32_t s_end_ms      = 0;
static uint32_t s_next_ms     = 0;
static uint32_t s_hold_ms     = BATTTEMP_DEFAULT_HOLD_MS;

static uint32_t s_batt_hold_ms  = BATTTEMP_DEFAULT_HOLD_MS;






// DHT22 드라이버에 따라 바뀔 것.
//extern int DHT22_ReadBlocking(float *outTempC, float *outRH);

// 네 전역과 포맷 규칙에 맞춤(0.1°C, 0..99%)
static inline uint16_t to_tenth_deg(float tC) {
    if (tC < 0) tC = 0; if (tC > 99.9f) tC = 99.9f;
    return (uint16_t)(tC * 10.0f + 0.5f);
}
static inline uint16_t to_rh_uint(float rh) {
    if (rh < 0) rh = 0; if (rh > 99.0f) rh = 99.0f;  // 100% 금지
    return (uint16_t)(rh + 0.5f);
}
/* ──────────────────────────────────────────────────────────────
 * DHT22
 * ────────────────────────────────────────────────────────────── */

// main에서 호출: DHT 하드 초기화
void BatteryTemp_DHT_Init(void)
{
    // APB1 Timer = 84MHz → timerBusFrequencyMHz = 84
    DHT_init(&g_dht, DHT_Type_DHT22, &htim7, 84, DHT_GPIO_Port, DHT_Pin);
}

// main의 HAL_GPIO_EXTI_Callback에서 호출해줄 포워더
void BatteryTemp_OnExti(uint16_t pin)
{
    if (pin == DHT_Pin) {
        DHT_pinChangeCallBack(&g_dht);
    }
}

// 블로킹 1회 읽기 래퍼 (성공=0, 실패=-1)
static int DHT22_ReadBlocking(float *outTempC, float *outRH)
{
    float t = 0.0f, h = 0.0f;
    if (!DHT_readData(&g_dht, &t, &h)) return -1;  // false면 실패
    if (outTempC) *outTempC = t;
    if (outRH)    *outRH    = h;
    return 0;
}












// 파일: BatteryTemp.c
void Measure_Service(void)
{
    if (!g_dht_req) return;
    g_dht_req = 0;



    // ── 재시도/디바운스 파라미터 ──────────────────────
    #ifndef DHT_READ_RETRIES
    #define DHT_READ_RETRIES          8      // 시도 횟수
    #endif
    #ifndef DHT_READ_RETRY_DELAY_MS
    #define DHT_READ_RETRY_DELAY_MS   10u    // 시도 간 대기(ms)
    #endif
    #ifndef DHT_FAIL_DEBOUNCE_COUNT
    #define DHT_FAIL_DEBOUNCE_COUNT   5      // 이 횟수 연속 실패 시 FAIL 표시
    #endif
    static uint8_t s_fail_consec = 0;
    // ────────────────────────────────────────────────

    float tC_raw = 0.0f, rh_raw = 0.0f;
    uint8_t ok = 0;

    for (int attempt = 0; attempt < DHT_READ_RETRIES; ++attempt) {
        if (DHT22_ReadBlocking(&tC_raw, &rh_raw) == 0) {
            // ① raw 유효성 검사(센서 명세 보수 범위)
            if (tC_raw >= -40.0f && tC_raw <= 80.0f &&
                rh_raw >=   0.0f && rh_raw <= 100.0f) {
                ok = 1;
                break;
            }
        }
        // 실패 시: 잠깐 쉬고 다시 시도 (ISR 금지 구역 아님)
        HAL_Delay(DHT_READ_RETRY_DELAY_MS);
    }

    if (ok) {
        // ② 보정 적용 (scale → offset)
        float tC_corr = tC_raw * Cal_TempC_Scale + Cal_TempC_Offset;
        float rh_corr = rh_raw * Cal_RH_Scale   + Cal_RH_Offset;

        DHT22_FAIL   = 0;
        s_fail_consec= 0;

        // ③ 전역 저장(표시 스펙 클램프는 기존 헬퍼 사용)
        Temperature = to_tenth_deg(tC_corr);  // 0.1°C
        Humidity    = to_rh_uint(rh_corr);    // 0..99%
    } else {
        // 이 사이클은 실패로 기록
        if (++s_fail_consec >= DHT_FAIL_DEBOUNCE_COUNT) {
            DHT22_FAIL = 1;   // 2사이클 연속 실패 시에만 화면에 '--' 노출
        }
        // 저장 값은 건드리지 않음(부분 갱신 로직이 숫자칸을 '-'로 덮음)
    }
}




/* ──────────────────────────────────────────────────────────────
 * 헬퍼: 안전 클램프
 * ────────────────────────────────────────────────────────────── */
static inline uint16_t clamp_u16_int(int v, int lo, int hi)
{
    if (v < lo) return (uint16_t)lo;
    if (v > hi) return (uint16_t)hi;
    return (uint16_t)v;
}

static uint32_t s_hdr_interval_ms = 100u;
void BatteryTemp_HeaderSetInterval(uint32_t ms) {
    s_hdr_interval_ms = (ms == 0u) ? 1u : ms;
}
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

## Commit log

2026-03-01 Update README with project overview and features
    Add detailed project description and features for STM32F4 DSP device
2026-03-01 Create Kicad
2026-03-01 Update README for clarity on device and code
    Clarified descriptions of the device's portability and code quality.
